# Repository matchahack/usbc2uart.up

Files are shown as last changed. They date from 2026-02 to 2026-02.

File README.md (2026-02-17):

# about

This project enable the user to connect and read/write their UART signals via USBC.

Feel free to read more about the design and use process [here](https://substack.com/home/post/p-186289458)

## PCB electronics design

In [`TOP-V2`](./TOP-V2), the KiCad files for the project schematic and layout are available, which enable BOM, Gerber, and Centroid generation for manufacture and assembly.

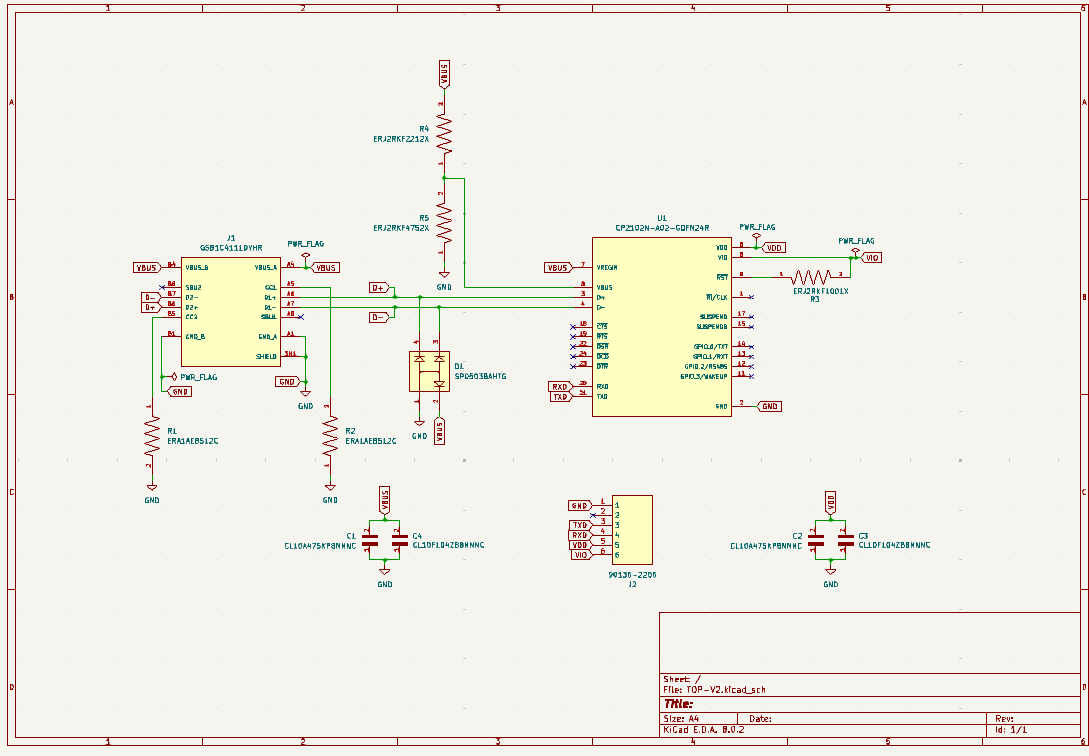
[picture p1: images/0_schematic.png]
schematic


> [!NOTE]
> The footprint paths will need to be changed for correct imports

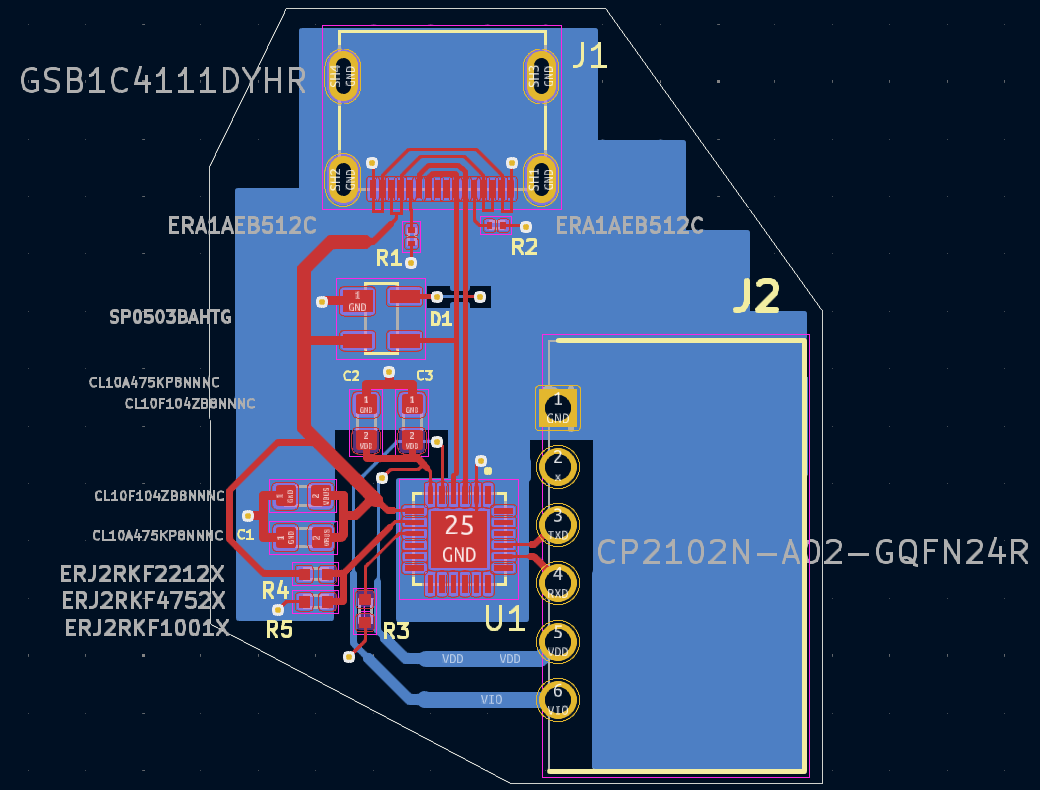
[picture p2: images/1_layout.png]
layout


Also the footprints and revelent 3D models needed to generate `.step` files for freeCAD housing design...

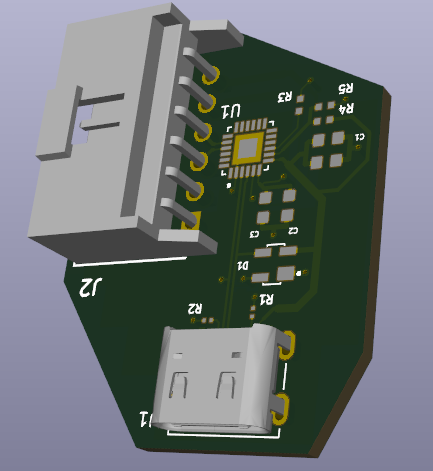
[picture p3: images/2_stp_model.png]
3d model


## PCB 3D-printed enclosure

In [`ENCLOSURE`](./ENCLOSURE), the freeCAD source files that enable us to generate a `.stl` - and therefore enable 3D-printed housing for the PCB

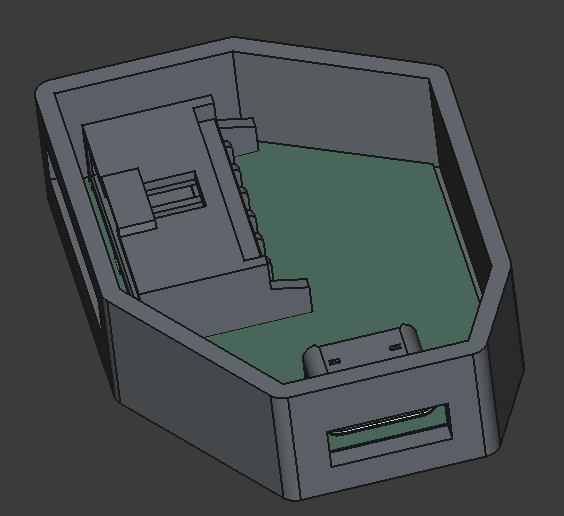
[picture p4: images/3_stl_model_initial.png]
initial


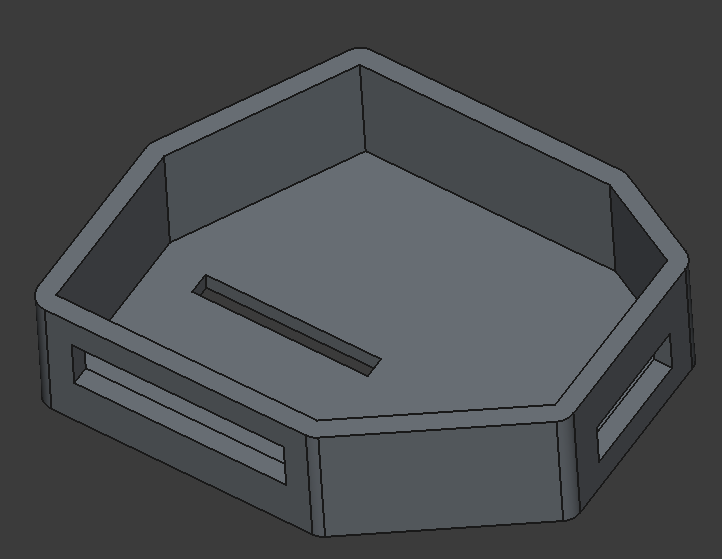
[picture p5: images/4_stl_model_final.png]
final


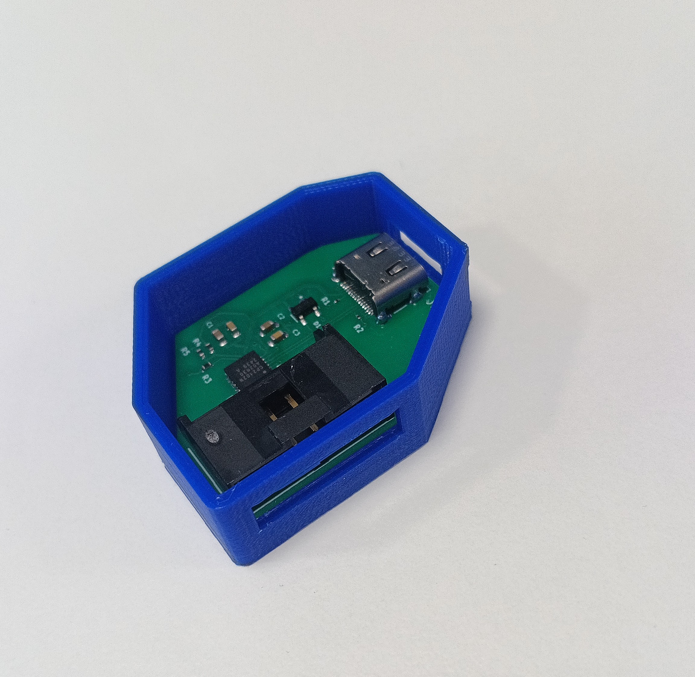
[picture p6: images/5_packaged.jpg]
packaged


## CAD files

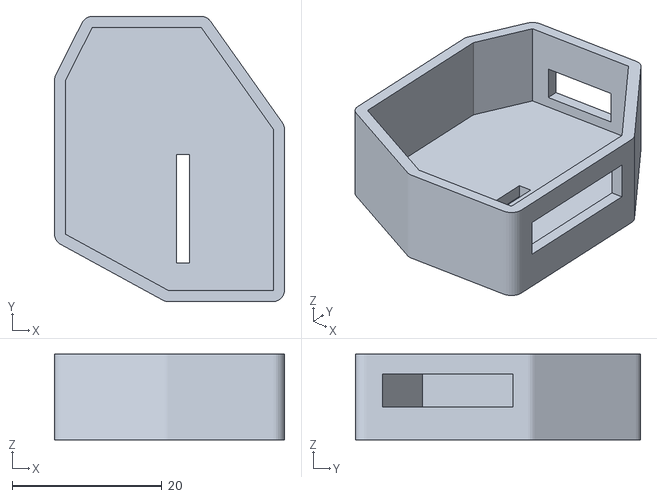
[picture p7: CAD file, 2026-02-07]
ENCLOSURE/enclosure_bottom-Body.stl
30.8 x 38.1 x 11.5

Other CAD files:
ENCLOSURE/enclosure_bottom.FCStd

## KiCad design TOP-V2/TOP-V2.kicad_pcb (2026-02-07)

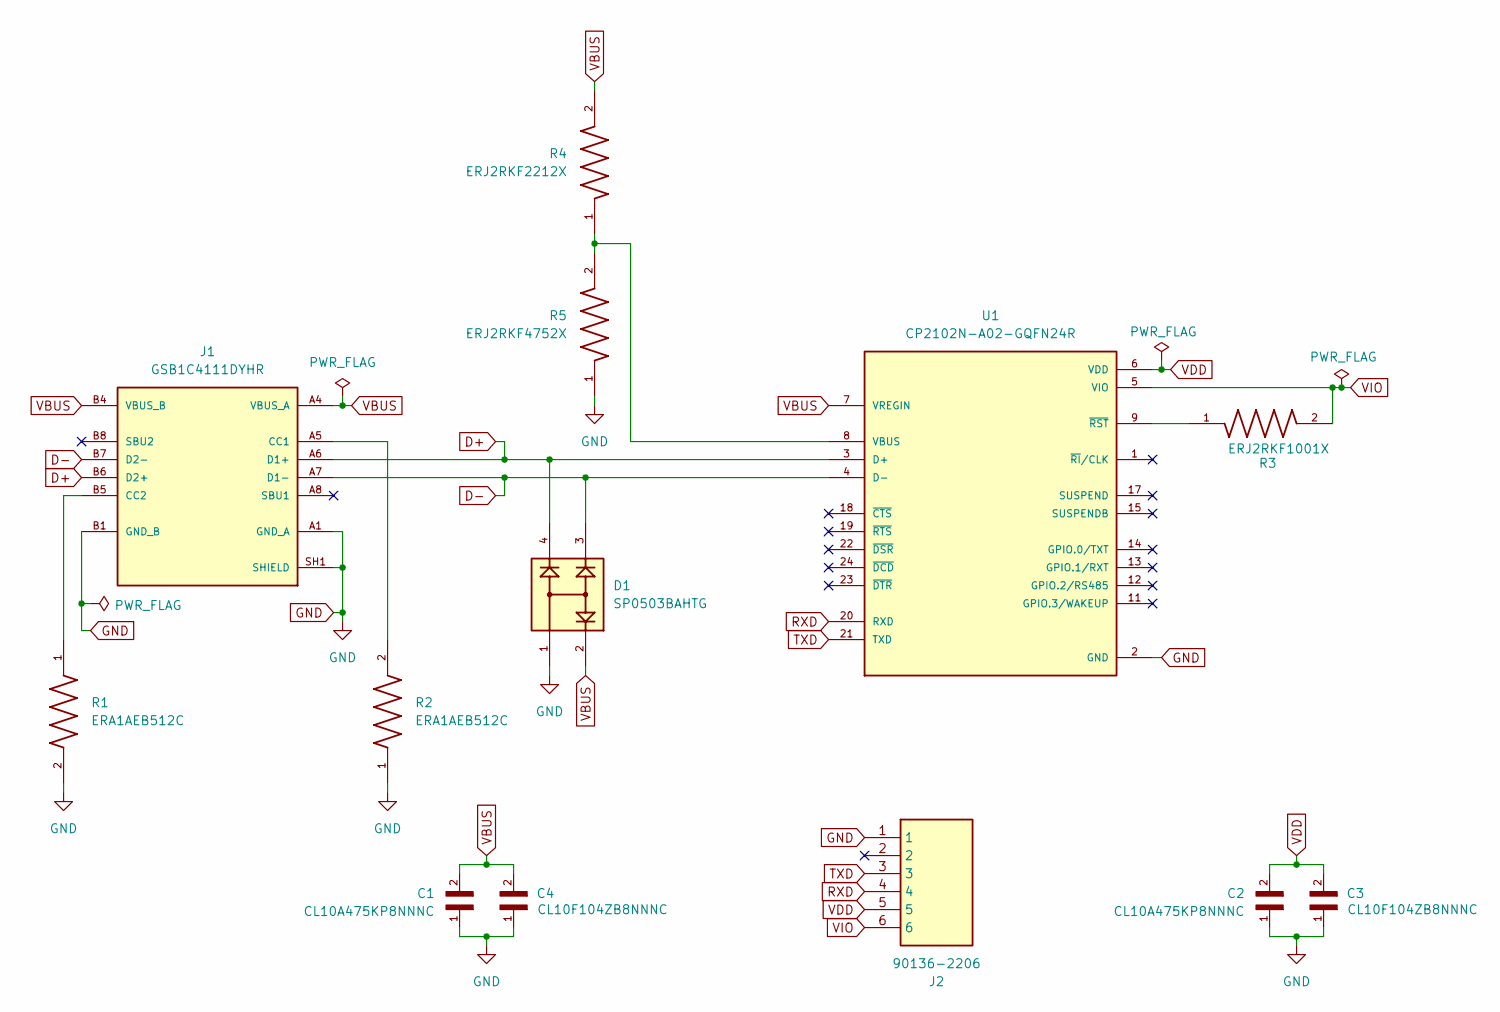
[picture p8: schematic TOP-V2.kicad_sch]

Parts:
C1, C2: CL10A475KP8NNNC; CAPC1608X90N; DigiKey_Part_Number 1276-1044-1-ND
C3, C4: CL10F104ZB8NNNC; CAPC1608X90N; DigiKey_Part_Number 1276-1012-1-ND
D1: SP0503BAHTG; SOT143; PARTREV N/A; DigiKey_Part_Number F2715CT-ND
J1: GSB1C4111DYHR; AMPHENOL_GSB1C4111DYHR; PARTREV AX1; DigiKey_Part_Number 664-GSB1C4111DYHRCT-ND
J2: 90136-2206; SHDRRA6W65P0X254_1X6_1859X1090X751P; Manufacturer_Part_Number 90136-2206
R1, R2: ERA1AEB512C; RES_ERA1AEB512C; PARTREV 3/1/2020; DigiKey_Part_Number 10-ERA-1AEB512CCT-ND
R3: ERJ2RKF1001X; RES_ERJ2RKF1001X; PARTREV 3/1/2020; DigiKey_Part_Number P1.00KLCT-ND
R4: ERJ2RKF2212X; RES_ERJ2RKF2212X; PARTREV 3/1/2020; DigiKey_Part_Number P22.1KLCT-ND
R5: ERJ2RKF4752X; RES_ERJ2RKF4752X; PARTREV 3/1/2020; DigiKey_Part_Number P47.5KLCT-ND
U1: CP2102N-A02-GQFN24R; QFN50P400X400X80-25N; PARTREV 1.3; DigiKey_Part_Number 336-5888-1-ND

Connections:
D+: D1.4, J1.A6 (D1+), J1.B6 (D2+), U1.3 (D+)
D-: D1.3, J1.A7 (D1-), J1.B7 (D2-), U1.4 (D-)
GND: C1.1, C2.1, C3.1, C4.1, D1.1, J1.A1 (GND_A), J1.A12 (GND_A), J1.B1 (GND_B), J1.B12 (GND_B), J1.SH1 (SHIELD), J1.SH2 (SHIELD), J1.SH3 (SHIELD), J1.SH4 (SHIELD), J2.1, R1.2, R2.1, R5.1, U1.2 (GND), U1.25 (GND)
unnamed: J1.A5 (CC1), R2.2
unnamed: J1.B5 (CC2), R1.1
unnamed: R4.1, R5.2, U1.8 (VBUS)
unnamed: R3.1, U1.9 (~RST)
RXD: J2.4, U1.20 (RXD)
TXD: J2.3, U1.21 (TXD)
VBUS: C1.2, C4.2, D1.2, J1.A4 (VBUS_A), J1.A9 (VBUS_A), J1.B4 (VBUS_B), J1.B9 (VBUS_B), R4.2, U1.7 (VREGIN)
VDD: C2.2, C3.2, J2.5, U1.6 (VDD)
VIO: J2.6, R3.2, U1.5 (VIO)

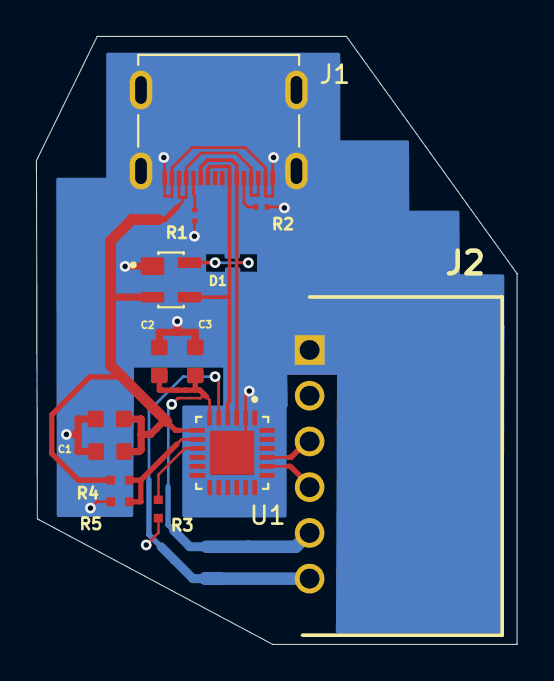
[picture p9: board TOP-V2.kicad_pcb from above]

Board: 2 copper layers, 26.7 x 33.8 mm, 13 parts (0 on the bottom side), 12 nets.
